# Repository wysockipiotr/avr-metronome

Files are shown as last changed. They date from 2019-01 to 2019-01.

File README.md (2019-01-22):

<h1 align="center">AVR Metronome</h1>
<h5 align="center">Metronome with speaker and remote vibration module</h5>

#### Modules
<table>
<tr>
  <td style="text-align: center">
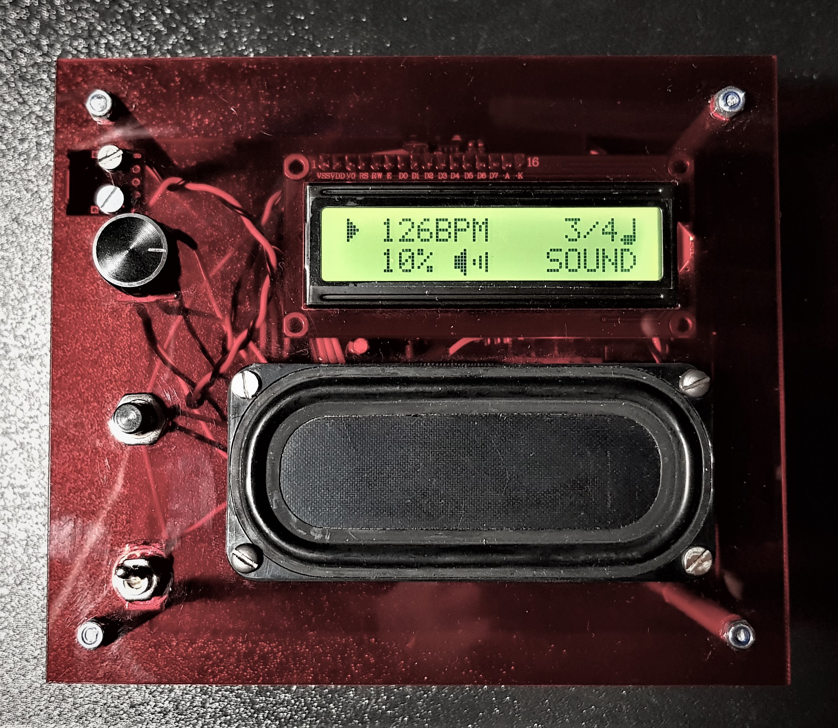
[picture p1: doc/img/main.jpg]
    
  </td>
  <td style="text-align: center">
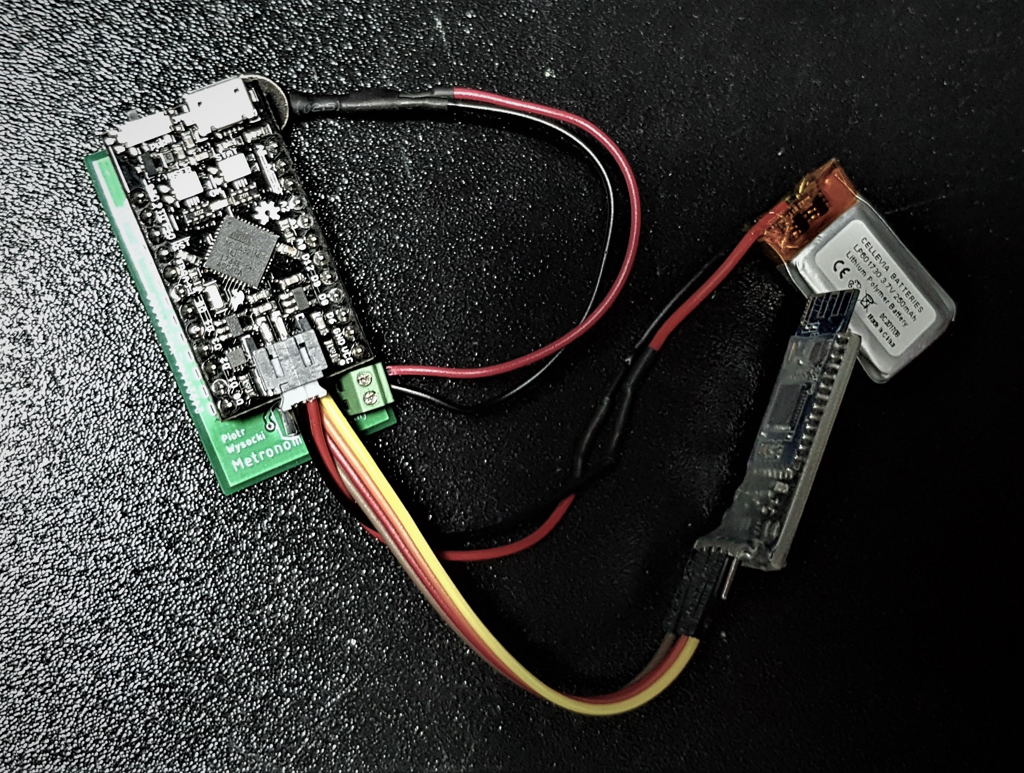
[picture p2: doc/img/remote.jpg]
    
  </td>
</tr>
</table>

#### Built with
- ATmega 168A-PU
- Qduino Mini
- MCP4161
- TPA2005D1
- HM-10 BLE

#### Features
- [x] Sound mode with volume control
- [x] Rotary encoder (with push button) user interface
- [x] BPM and basic signatures control
- [x] Tap tempo (button)
- [x] PWM LCD backlight (dimming after a period of inactivity)
- [x] Storing metronome settings in the internal EEPROM
- [x] Custom character display
- [x] Remote vibration module (BLE)
- [x] Default idle state for remote module, receiving disable signal
- [x] MicroUSB charging
- [x] Adjustable sound pitch

#### Project structure
```c
+-- 
   +-- README.md
   +-- .gitignore
   +-- doc
      +-- eagle
         +-- main
         +-- remote
   +-- metronome          // ATmega metronome main module directory
      +-- Makefile        // compiler and programmer config
      +-- main.c          // entry point
      +-- setup.h         // device main settings
      +-- util.h          // helper macros
      +-- global.h        // extern declarations
      +-- lcd.h           // LCD 2x16 interfacing in 4-bit mode
      +-- lcd.c
      +-- eeprom.h
      +-- eeprom.c
      +-- metronome.h     // core logic of the metronome, ISR handlers
      +-- metronome.c
      +-- usart.h         // serial communication with HM-10 BLE module
      +-- usart.c
      +-- mcp41xx.h       // MCP4161 Digital potentiometer SPI interfacing
      +-- mcp41xx.c
   +-- remote_module      // Qduino (Arduino) remote vibrating module sketch directory
      +-- README.md
      +-- remote_module.ino
```

#### Setup
##### Prerequisites
- make
- avrdude
- avr-gcc
##### Makefile
Override parameters in Makefile to suit your hardware configuration. Here, Arduino Uno is used as an in-system programmer.
```diff
- MCU = atmega168
+ MCU = <your_unit>

- PROGRAMMER_TYPE = avrisp
- PROGRAMMER_ARGS = -b 19200 -P COM4
+ PROGRAMMER_TYPE = <your_programmer_type>
+ PROGRAMMER_ARGS = -b <baud_rate> -P <device_name>
```
##### Deployment
Use `make flash` to compile and save program in flash memory (using `avrdude`). Use `make size` to find out about the size of the program.

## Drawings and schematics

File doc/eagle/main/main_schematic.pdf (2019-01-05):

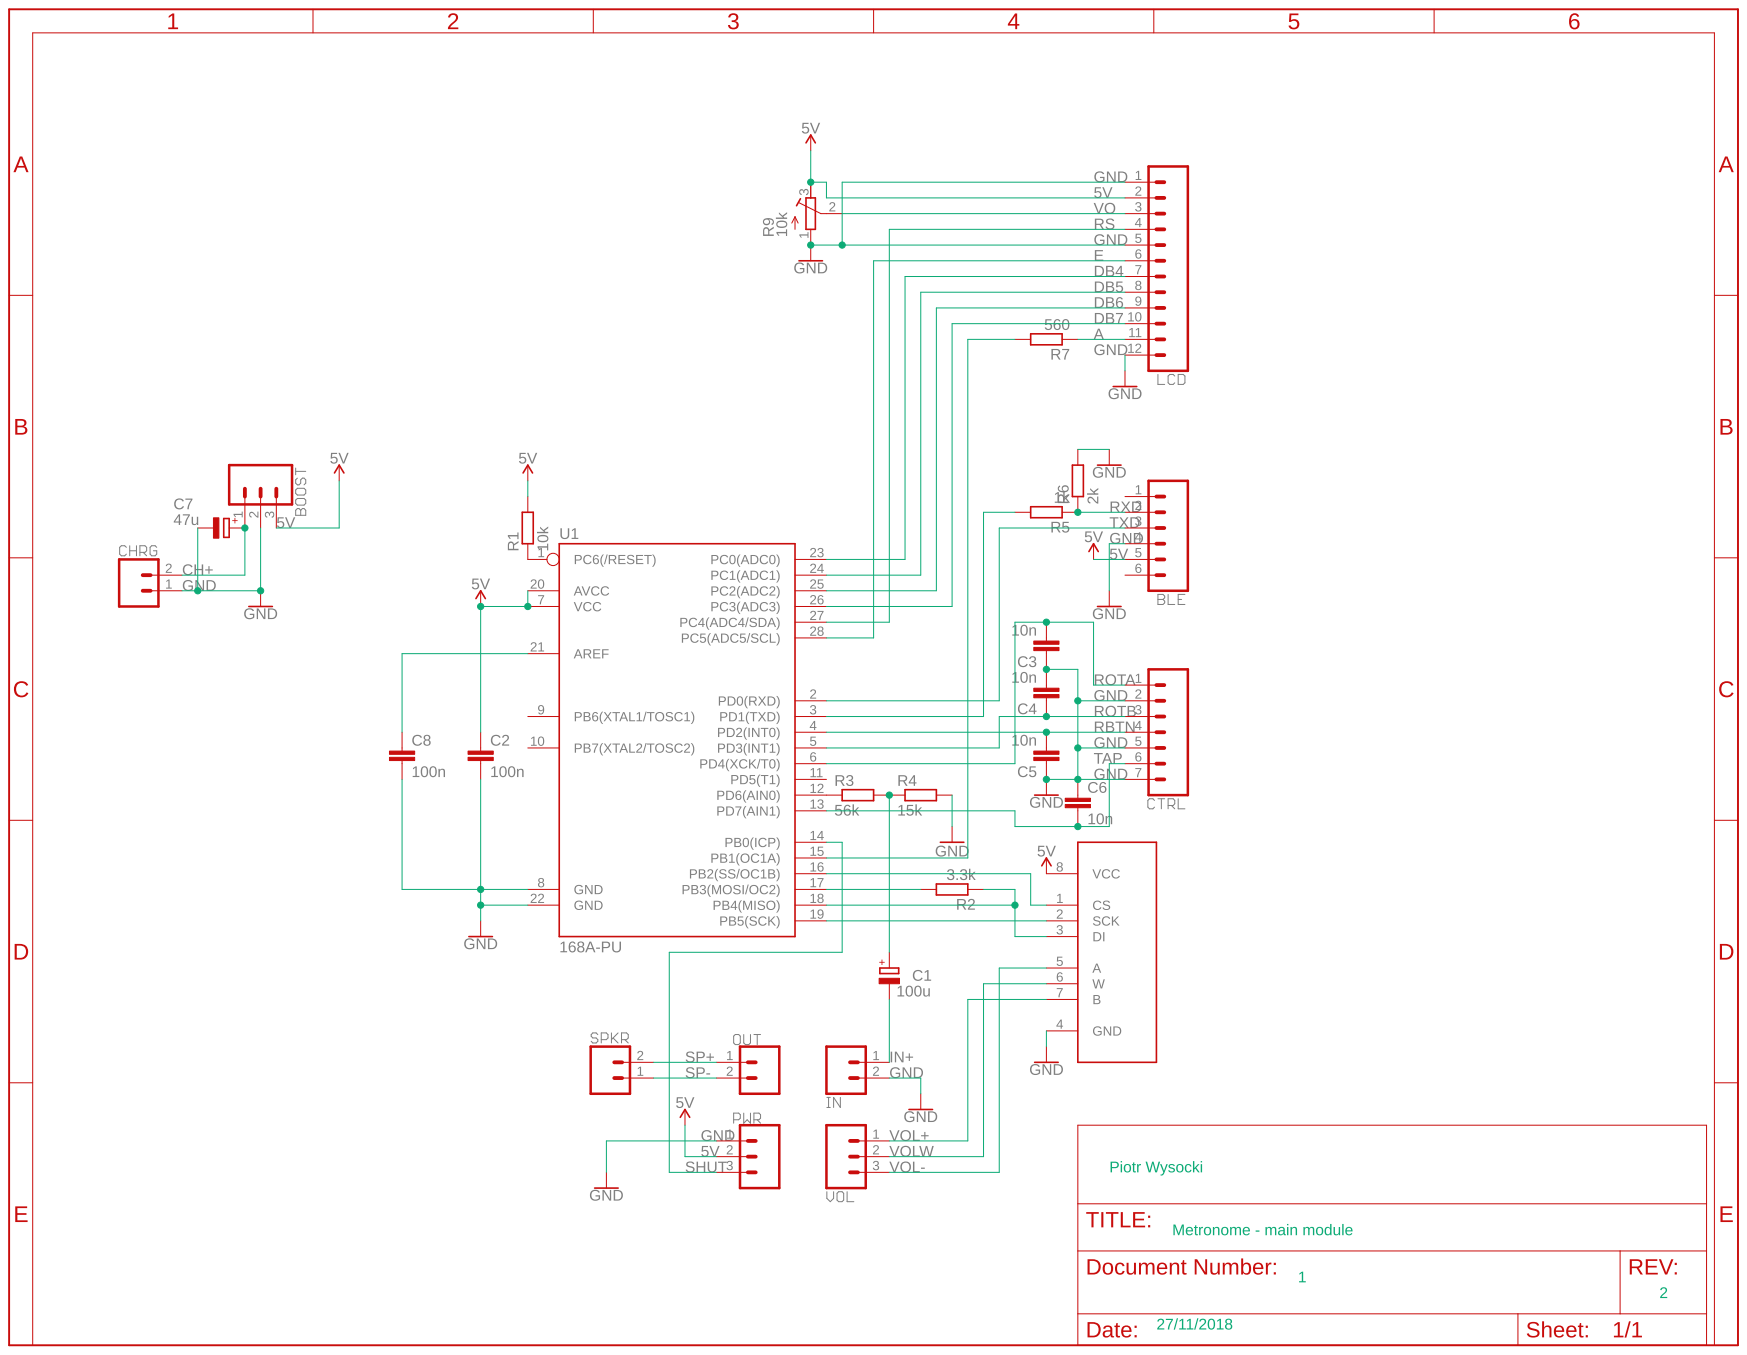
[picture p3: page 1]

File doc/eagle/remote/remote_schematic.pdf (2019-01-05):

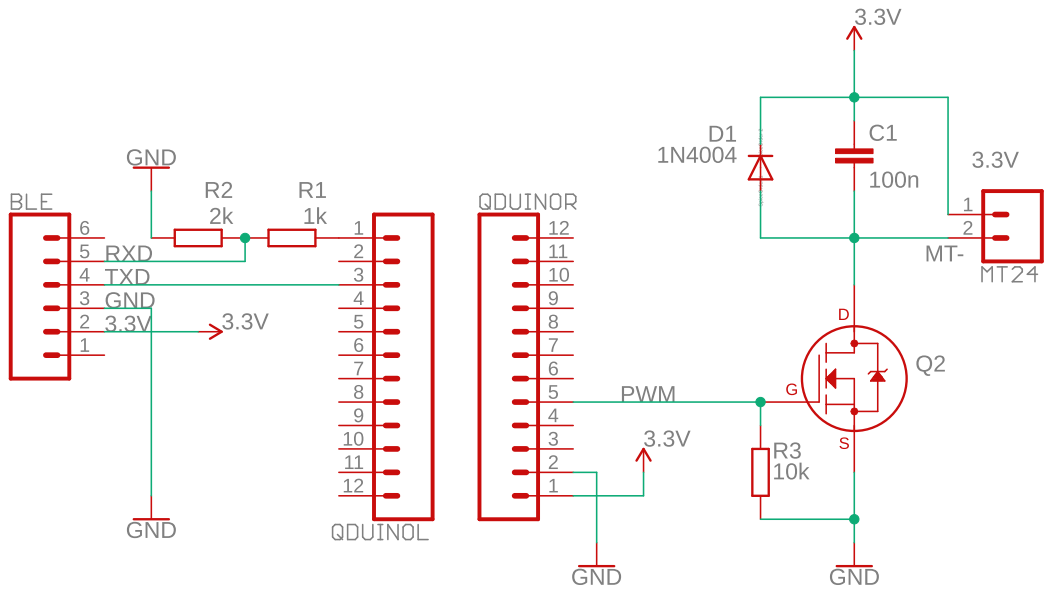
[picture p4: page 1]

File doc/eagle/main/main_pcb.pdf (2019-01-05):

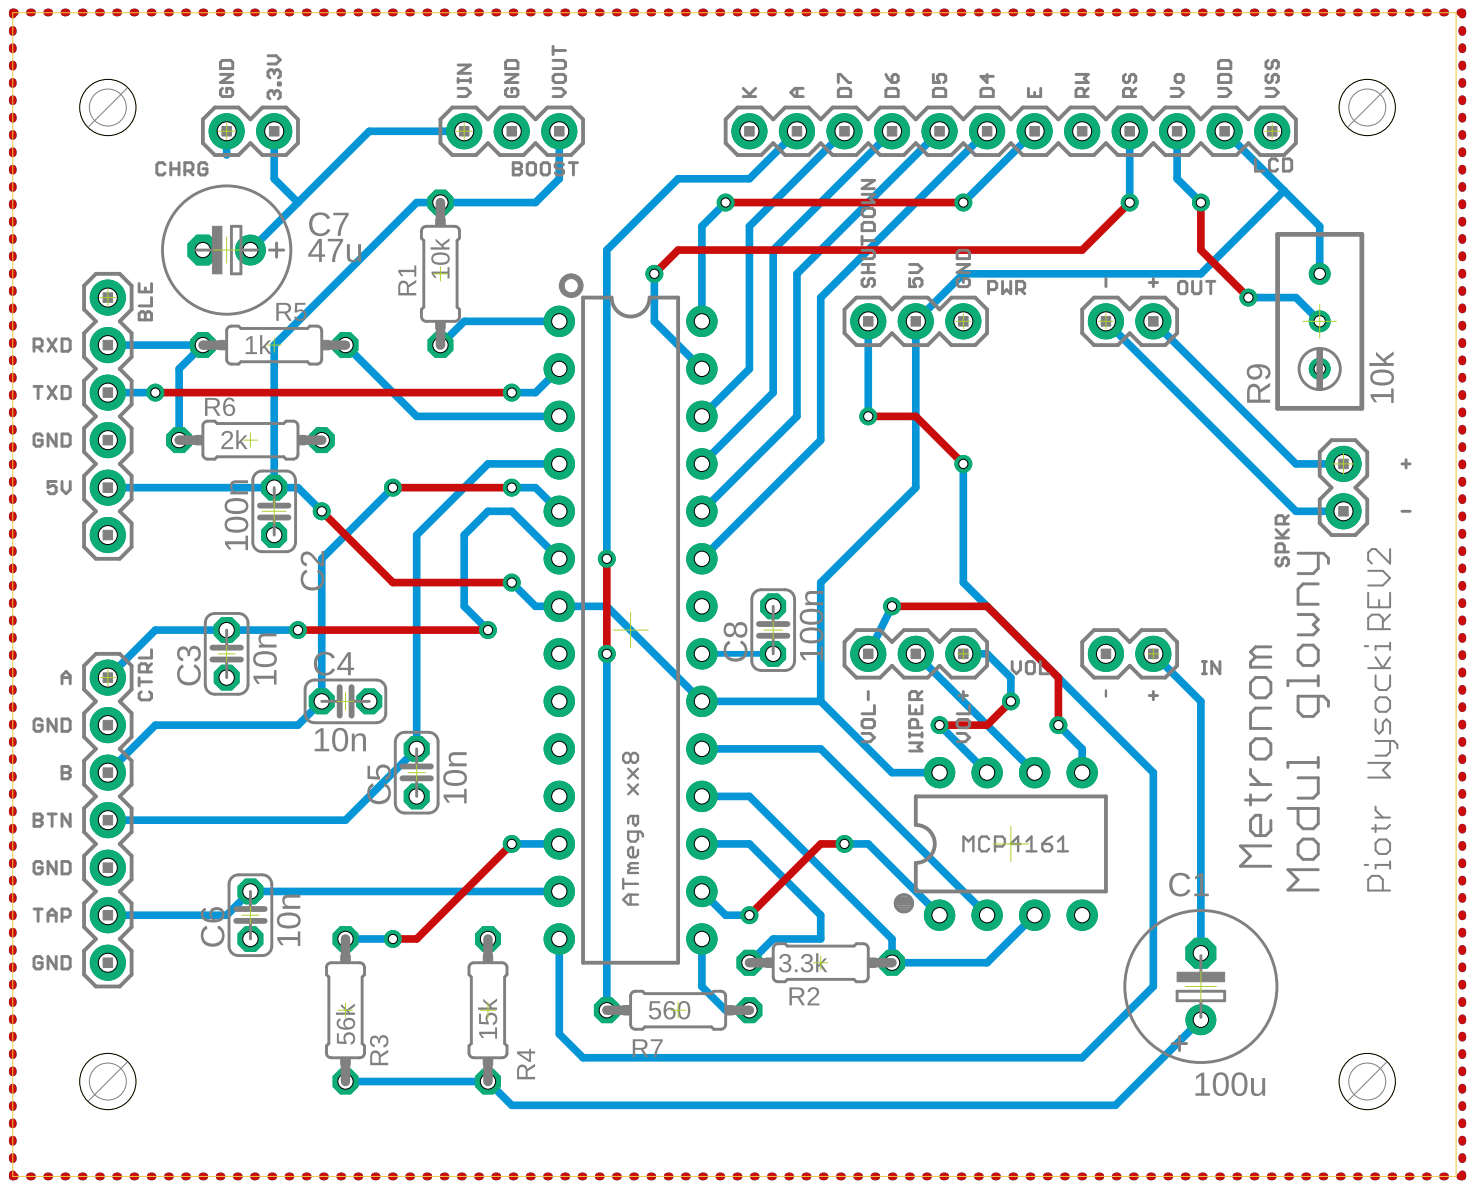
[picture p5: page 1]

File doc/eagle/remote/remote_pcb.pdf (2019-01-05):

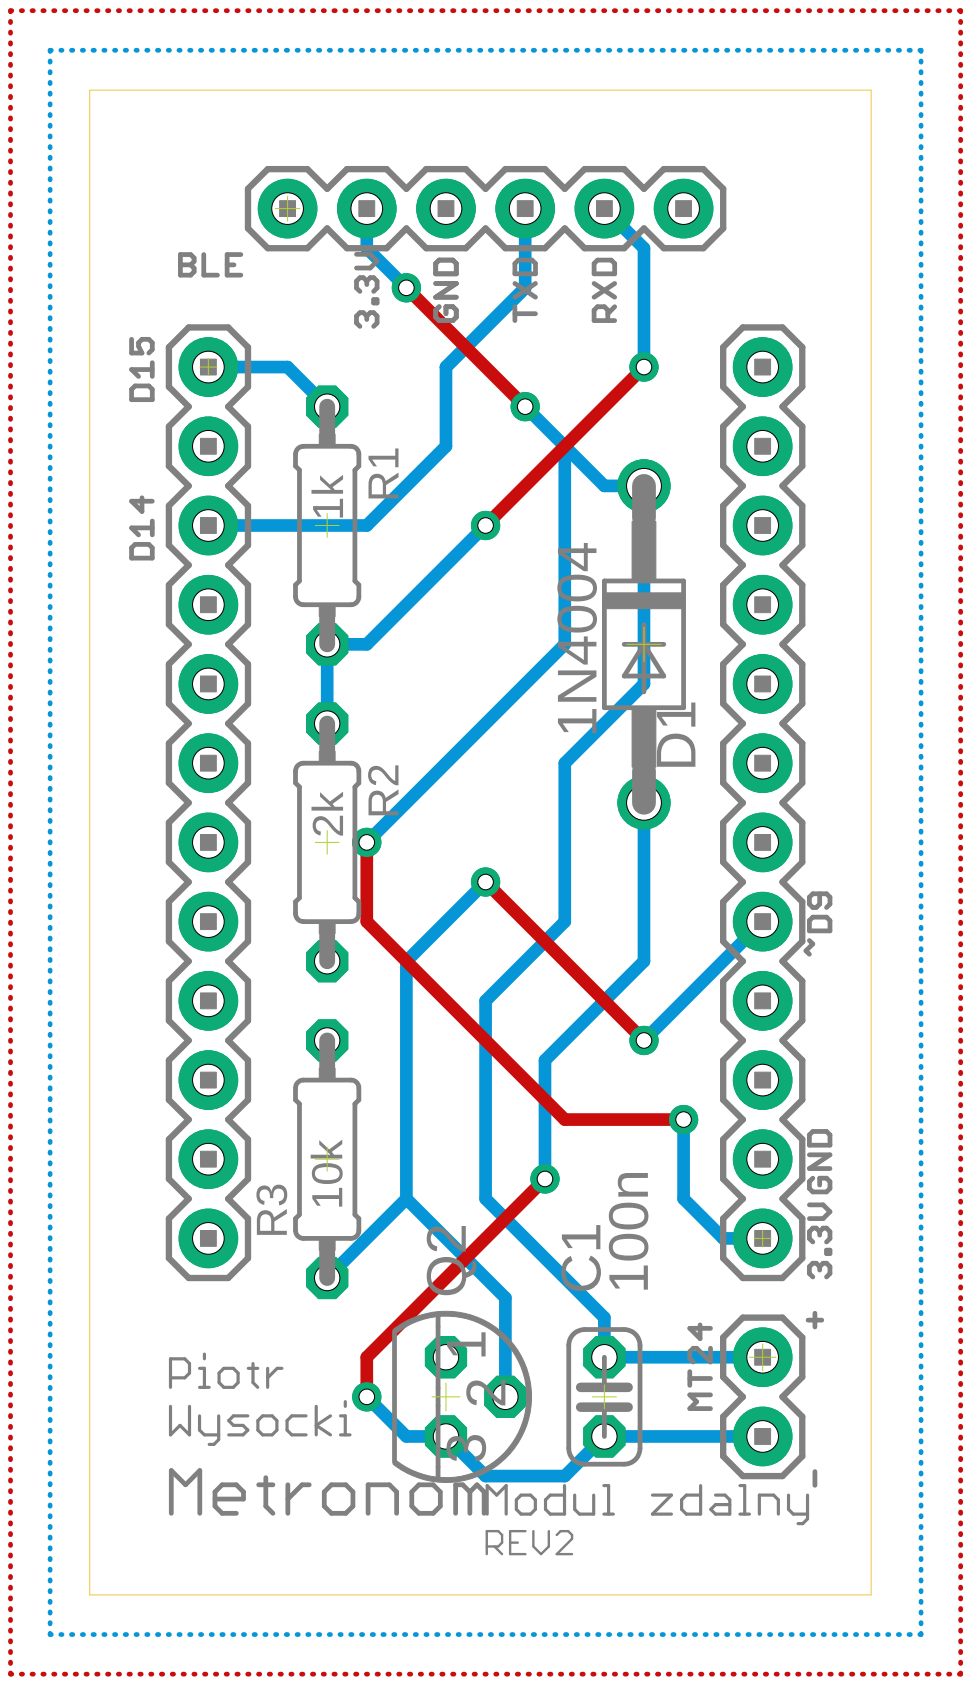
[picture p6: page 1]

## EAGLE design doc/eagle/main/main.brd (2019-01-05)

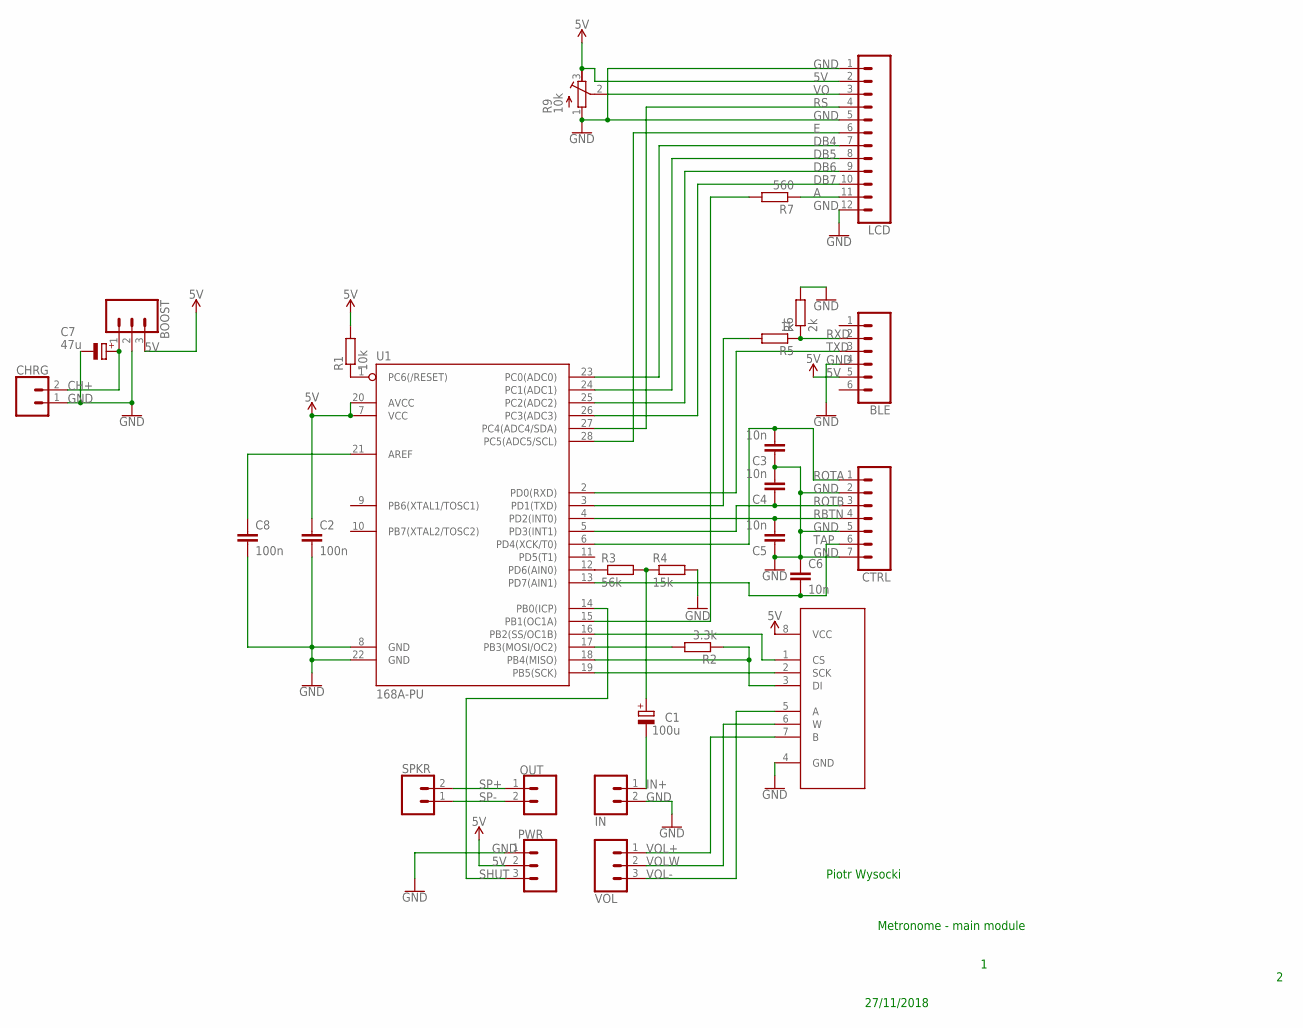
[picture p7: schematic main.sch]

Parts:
BLE: CONN_06SILK_FEMALE_PTH; 1X06
BOOST: CONN_03; 1X03
C1: 100u; E3,5-8
C2, C8: 100n; C025-024X044
C3, C4, C5, C6: 10n; C025-024X044
C7: 47u; E2,5-7
CHRG: CONN_02; 1X02
CTRL: CONN_07; 1X07
IN: CONN_02; 1X02
LCD: CONN_12; 1X12
MCP4161: MCP41XXX; DIP08
OUT: CONN_02; 1X02
PWR: CONN_03; 1X03
R1: 10k; 0204/7
R2: 3.3k; 0204/7
R3: 56k; 0204/7
R4: 15k; 0204/7
R5: 1k; 0204/7
R6: 2k; 0204/7
R7: 560; 0204/7
R9: 10k; RTRIM3296W
SPKR: CONN_02; 1X02
U1: 168A-PU; DIP28
VOL: CONN_03; 1X03

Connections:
5V: BLE.5, BOOST.3, C2.1, LCD.2, MCP4161.8 (VCC), PWR.2, R1.2, R9.3 (E), U1.7 (VCC), U1.20 (AVCC)
A: LCD.11, R7.1
CH+: BOOST.1, C7.+, CHRG.2
DB4: LCD.7, U1.23 (PC0(ADC0))
DB5: LCD.8, U1.24 (PC1(ADC1))
DB6: LCD.9, U1.25 (PC2(ADC2))
DB7: LCD.10, U1.26 (PC3(ADC3))
E: LCD.6, U1.28 (PC5(ADC5/SCL))
GND: BLE.4, BOOST.2, C2.2, C3.1, C4.2, C5.1, C6.1, C7.-, C8.2, CHRG.1, CTRL.2, CTRL.5, CTRL.7, IN.2, LCD.1, LCD.5, LCD.12, MCP4161.4 (GND), PWR.1, R4.2, R6.2, R9.1 (A), U1.8 (GND), U1.22 (GND)
IN+: C1.-, IN.1
unnamed: MCP4161.2 (SCK), U1.19 (PB5(SCK))
unnamed: MCP4161.1 (CS), U1.16 (PB2(SS/OC1B))
unnamed: R1.1, U1.1 (PC6(/RESET))
unnamed: R2.2, U1.17 (PB3(MOSI/OC2))
unnamed: MCP4161.3 (DI), R2.1, U1.18 (PB4(MISO))
unnamed: C8.1, U1.21 (AREF)
unnamed: R3.1, U1.12 (PD6(AIN0))
unnamed: C1.+, R3.2, R4.1
unnamed: R5.2, U1.3 (PD1(TXD))
unnamed: R7.2, U1.15 (PB1(OC1A))
RBTN: C5.2, CTRL.4, U1.4 (PD2(INT0))
ROTA: C3.2, CTRL.1, U1.6 (PD4(XCK/T0))
ROTB: C4.1, CTRL.3, U1.5 (PD3(INT1))
RS: LCD.4, U1.27 (PC4(ADC4/SDA))
RXD: BLE.2, R5.1, R6.1
SHUT: PWR.3, U1.14 (PB0(ICP))
SP+: OUT.1, SPKR.2
SP-: OUT.2, SPKR.1
TAP: C6.2, CTRL.6, U1.13 (PD7(AIN1))
TXD: BLE.3, U1.2 (PD0(RXD))
VO: LCD.3, R9.2 (S)
VOL+: MCP4161.7 (B), VOL.1
VOL-: MCP4161.5 (A), VOL.3
VOLW: MCP4161.6 (W), VOL.2

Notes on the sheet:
Metronome - main module
Piotr Wysocki
27/11/2018

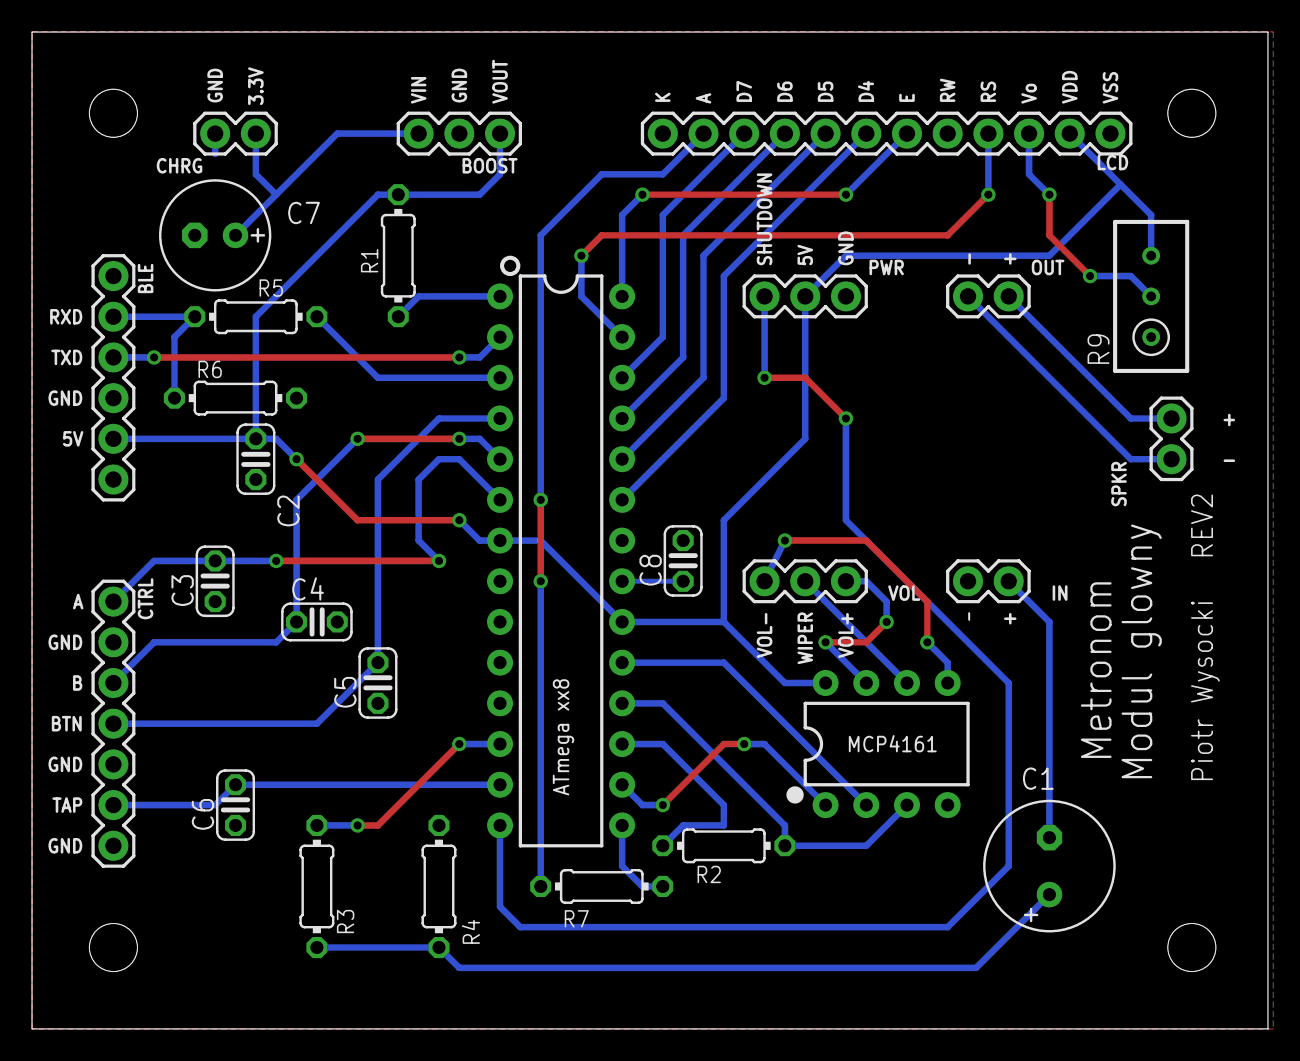
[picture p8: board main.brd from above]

Board: 2 copper layers, 77.1 x 62.2 mm, 28 parts (0 on the bottom side), 34 nets.

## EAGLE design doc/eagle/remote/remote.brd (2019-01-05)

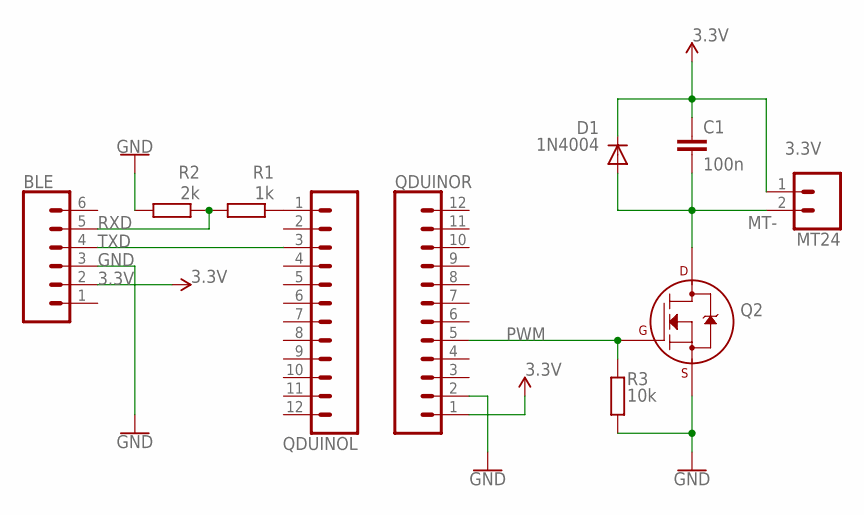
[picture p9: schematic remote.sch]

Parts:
BLE: CONN_06SILK_FEMALE_PTH; 1X06
C1: 100n; C025-024X044
D1: 1N4004; DO41-10
MT24: CONN_02; 1X02
Q2: 2N7000_TO92; TO-92
QDUINOL: CONN_12; 1X12
QDUINOR: CONN_12; 1X12
R1: 1k; 0204/7
R2: 2k; 0204/7
R3: 10k; 0204/7

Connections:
3.3V: BLE.2, C1.1, D1.C, MT24.1, QDUINOR.1
GND: BLE.3, Q2.1 (S), QDUINOR.2, R2.2, R3.2
MT-: C1.2, D1.A, MT24.2, Q2.3 (D)
unnamed: QDUINOL.1, R1.1
PWM: Q2.2 (G), QDUINOR.5, R3.1
RXD: BLE.5, R1.2, R2.1
TXD: BLE.4, QDUINOL.3

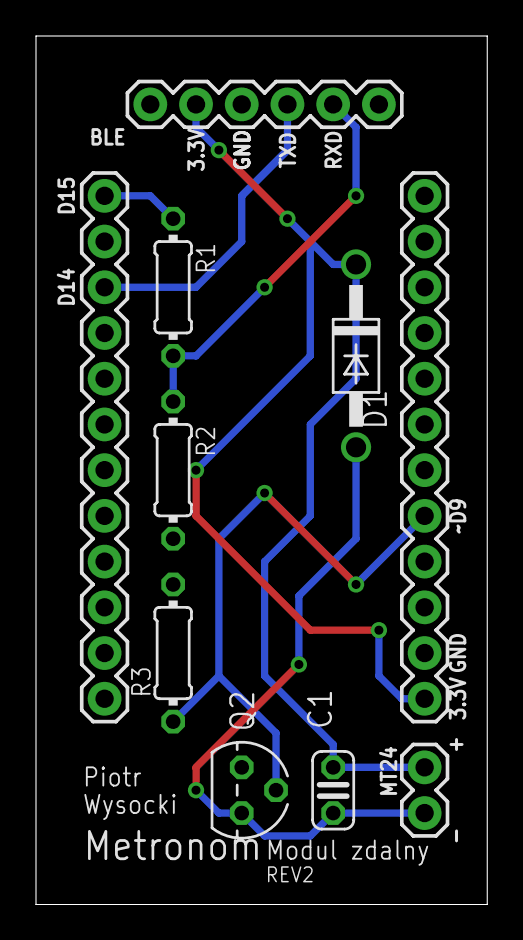
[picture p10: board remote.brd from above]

Board: 2 copper layers, 25.1 x 48.2 mm, 10 parts (0 on the bottom side), 7 nets.

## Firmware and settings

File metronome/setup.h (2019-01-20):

#ifndef __setup_h__
#define __setup_h__

#ifdef F_CPU
    #if F_CPU != 8000000
        #undef F_CPU
        #define F_CPU 8000000
    #endif
#endif

#ifndef BAUD
    #define BAUD 9600
#endif

#include <avr/io.h>
#include "lcd.h"

#define LCD_DIR                     DDRC  
#define LCD_DATA_DIR                DDRC
#define LCD_CMD_DIR                 DDRC
#define LCD_DATA_PORT               DDRC 
#define LCD_CMD_PORT                PORTC
#define LCD_PORT                    PORTC 
#define RS                          PC4 
#define EN                          PC5
#define LCD_D4                      PC0 
#define LCD_D5                      PC1   
#define LCD_D6                      PC2   
#define LCD_D7                      PC3   

#define ROTARY_PORT                 PORTD
#define ROTARY_BTN                  PD2
#define ROTARY_PIN                  PIND
#define ROTARY_DIR                  DDRD
#define ROTARY_A                    PD3
#define ROTARY_B                    PD4

#define SPEAKER_DIR                 DDRD
#define SPEAKER_PORT                PORTD
#define SPEAKER                     PD6
#define SPEAKER_PIN                 PIND

#define TAP_DIR                     DDRD
#define TAP_PORT                    PORTD
#define TAP_PIN                     PIND
#define TAP_BTN                     PD7

#define SHUTDOWN_DIR                DDRB
#define SHUTDOWN_PORT               PORTB
#define SHUTDOWN_PIN                PINB
#define SHUTDOWN                    PB0

#define BACKLIGHT_DIR               DDRB
#define BACKLIGHT_PORT              PORTB
#define BACKLIGHT_PIN               PINB
#define BACKLIGHT                   PB1

// SPI
#define SPI_POT_SS                  PB2
#define SPI_POT_SS_PORT             PORTB
#define SPI_POT_SS_PIN              PINB
#define SPI_POT_SS_DDR              DDRB

#define SPI_MOSI                    PB3
#define SPI_MOSI_PORT               PORTB
#define SPI_MOSI_PIN                PINB
#define SPI_MOSI_DDR                DDRB

#define SPI_MISO                    PB4
#define SPI_MISO_PORT               PORTB
#define SPI_MISO_PIN                PINB
#define SPI_MISO_DDR                DDRB

#define SPI_SCK                     PB5
#define SPI_SCK_PORT                PORTB
#define SPI_SCK_PIN                 PINB
#define SPI_SCK_DDR                 DDRB

#define TAP_TIMER_INITIAL_OFFSET    0x83
#define MIN_TAP_INTERVAL            150u
#define MAX_TAP_INTERVAL            2000u

#define BACKLIGHT_DURATION          20000u  // 20s
#define DEFAULT_BRIGHTNESS          120u

#define MIN_BPM                     30u
#define MAX_BPM                     400u
#define MIN_VOLUME                  0u
#define MAX_VOLUME                  100u
#define VOLUME_STEP                 5u
#define DEFAULT_BPM                 140u
#define DEFAULT_VOL                 5u
#define DEFAULT_SIGNATURE           4u
#define MIN_SIGNATURE               1u 
#define MAX_SIGNATURE               16u
#define G                           33u
#define CIS                         47u
#define TAP_NOTE                    120u
#define TAP_BEEP_DURATION           100u

#define BPM_CURSOR_POS              0u
#define SIG_CURSOR_POS              1u 
#define VOL_CURSOR_POS              2u
#define MODE_CURSOR_POS             3u
#define PITCH_CURSOR_POS            4u

#define PARAM_EDIT_SYMBOL           LCD_ARROWS_CHAR
#define PARAM_SELECT_SYMBOL         LCD_FAT_ARROW_CHAR

#define SOUND_LABEL                 "SOUND"
#define VIBRT_LABEL                 "VIBRT"

#define SOUND_MODE                  0u 
#define VIBRT_MODE                  1u
#define DEFAULT_MODE                SOUND_MODE

#define NUMBER_OF_MODES             2
// #define NUMBER_OF_SIGNATURES        4

#define EEPROM_STORE_ADR            0
#define EEPROM_STORE_BPM            ((uint16_t*)EEPROM_STORE_ADR)
#define EEPROM_STORE_VOL            ((uint8_t*)EEPROM_STORE_ADR + 2)
#define EEPROM_STORE_SIG            ((uint8_t*)EEPROM_STORE_ADR + 3)
#define EEPROM_STORE_MODE           ((uint8_t*)EEPROM_STORE_ADR + 4)
#define EEPROM_STORE_PITCH          ((uint8_t*)EEPROM_STORE_ADR + 5)

// sound scale
#define D2                          89
#define Dx2                         84
#define E2                          79
#define F2                          75
#define Fx2                         71
#define G2                          67
#define Gx2                         63
#define A2                          59
#define Ax2                         56
#define B2                          53
#define C3                          50
#define Cx3                         47
#define D3                          44
#define Dx3                         42
#define E3                          40
#define F3                          37
#define Fx3                         35
#define G3                          33

#define DEFAULT_PITCH_INDEX         11u
#define MAX_PITCH_INDEX             11u
#define MIN_PITCH_INDEX             0u
#define ACCENT_PITCH_OFFSET         6u

#endif //__setup_h__

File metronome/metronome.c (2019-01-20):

#include "metronome.h"
#include "eeprom.h"
#include "global.h"
#include "mcp41xx.h"
#include "usart.h"
#include "util.h"

#include <avr/interrupt.h>
#include <avr/pgmspace.h>
#include <avr/power.h>
#include <stdio.h>
#include <util/delay.h>

// load initial settings, setup peripherals and ports
inline static void setup(void);

// enable interrupts, specify pin change interrupts mask
inline static void init_interrupts(void);

// init timer2 (tap tempo timer), enable its overflow interrupt
inline static void init_tap_timer(void);

// init timer0 (sound synthesize timer)
inline static void init_sound_timer(void);

// main metronome action loop
inline static void loop(void);

// play note with a given wavelength for a given duration
inline static void play_note(uint16_t wavelength, uint8_t duration);

// refresh displayed values and cursor arrow position
inline static void update_display(void);

// update value of the currently selected parameter by the given delta
inline static void update_active_param(int delta);

// recalc beep and silence durations regarding current bpm value
inline static void recalc_durations(void);

// init timer1 in Fast PWM mode (for dimming lcd backlight)
inline static void init_dimmer_pwm(void);

// set lcd backlight brightness (PWM)
inline static void set_brightness(uint8_t brightness);

inline static uint8_t get_tone(uint8_t tone_index);

const static uint8_t tone_table[] PROGMEM = {D2, Dx2, E2, F2, Fx2, G2, Gx2, A2, Ax2,
                                             B2, C3, Cx3, D3, Dx3, E3, F3, Fx3, G3};

void metronome(void) {
    setup();
    loop();
}

void handle_portd_pin_change(void) {
    set_brightness(DEFAULT_BRIGHTNESS);
    backlight_on = true;
    backlight_time_counter = 0u;

    clearBit(SPEAKER_DIR, SPEAKER);

    if (bit_is_clear(ROTARY_PIN, ROTARY_BTN)) {
        if (mode == VIBRT_MODE && edit_active) {
            transmit_metronome(bpm, signature);
        } 
        if (mode == SOUND_MODE && edit_active) {
            transmit_metronome_off();
        }
        edit_active = !edit_active;
        cursor_symbol = (edit_active) ? PARAM_EDIT_SYMBOL : PARAM_SELECT_SYMBOL;
        update_display();
    }

    if (bit_is_clear(ROTARY_PIN, ROTARY_A)) {
        if (bit_is_clear(ROTARY_PIN, ROTARY_B)) {
            // left rotate
            if (!edit_active) {
                if (cursor) {
                    --cursor;
                } else {
                    cursor = 4u;
                }
                if (mode == VIBRT_MODE) {
                    if (cursor == 2u) {
                        cursor = 1u;
                    } else if (cursor == 4u) {
                        cursor = 3u;
                    }
                }
            } else {
                update_active_param(-1);
            }
        } else {
            // right rotate
            if (!edit_active) {
                ++cursor;
                cursor %= 5u;
                if (mode == VIBRT_MODE) {
                    if (cursor == 2u) {
                        cursor = 3u;
                    } else if (cursor == 4u) {
                        cursor = 0u;
                    }
                }
            } else {
                update_active_param(1);
            }
        }

        recalc_durations();

        update_display();

        // force a little down time before continuing
        _delay_ms(2);

        // wait until R1 comes back high
        while (bit_is_clear(ROTARY_PIN, ROTARY_A)) {
        }
    }

    if (bit_is_clear(TAP_PIN, TAP_BTN)) {
        edit_active = false;
        cursor_symbol = (edit_active) ? PARAM_EDIT_SYMBOL : PARAM_SELECT_SYMBOL;

        bool tap_interval_is_within_range = within(tap_interval_counter, MIN_TAP_INTERVAL, MAX_TAP_INTERVAL);

        // beep during tap
        if (tap_interval_is_within_range || !tap_started) {
            sound_locked = false;
            if (mode == VIBRT_MODE) setBit(SHUTDOWN_PORT, SHUTDOWN);
            play_note(TAP_NOTE, TAP_BEEP_DURATION);
            sound_locked = true;
        }

        // tap tempo handler
        if (tap_started) {
            if (tap_interval_is_within_range) {
                t_beep = tap_interval_counter >> 4;
                t_sleep = tap_interval_counter - t_beep;
                bpm = 60000u / tap_interval_counter;
                update_display();
            }
        } else {
            tap_started = true;
            sound_locked = true;
        }
        // start counting
        tap_interval_counter = 0u;
        //TCCR2A = 0;
        TCCR2B = 0x4;
        TCNT2 = TAP_TIMER_INITIAL_OFFSET;  // 131 ticks until overflow (overflow every 1ms)
    }
}

void handle_timer2_overflow(void) {
    // handle tap tempo
    if (tap_interval_counter <= MAX_TAP_INTERVAL) {
        ++tap_interval_counter;
        // TCNT2 = TAP_TIMER_INITIAL_OFFSET;
    } else {
        // dismiss tap tempo in case of timeout (over 2000ms)
        if (tap_started) {
            tap_started = false;
            if (mode == VIBRT_MODE) {
                transmit_metronome(bpm, signature);
                clearBit(SHUTDOWN_PORT, SHUTDOWN);
            }
            sound_locked = false;
        }
        //TCCR2B &= ~(TCCR2B & 0x7);
    }

    // handle backlight and settings storage
    if (backlight_time_counter <= BACKLIGHT_DURATION) {
        ++backlight_time_counter;
    } else {
        if (backlight_on) {
            backlight_on = false;
            set_brightness(0);
            //backlight_time_counter = 0u;

            // store current metronome settings in eeprom (bpm, signature, volume, mode)
            eeprom_store_settings();
        }
    }

    // restart 1ms measure
    TCNT2 = TAP_TIMER_INITIAL_OFFSET;
}

inline static void update_display(void) {
    if (cursor <= MODE_CURSOR_POS) {
        // Menu page (1): bpm, signature, volume (in sound mode), mode

        snprintf(firstLineBuffer, 17, "%c %3uBPM %c %2u/4 ",
                 cursorVisible(cursor, 0, cursor_symbol),
                 bpm,
                 cursorVisible(cursor, 1, cursor_symbol),
                 signature);

        if (mode == SOUND_MODE) {
            // second line of menu in sound mode

            snprintf(secondLineBuffer, 17, "%c %2u%%    %c %s",
                     cursorVisible(cursor, 2, cursor_symbol),
                     volume % 100,
                     cursorVisible(cursor, 3, cursor_symbol),
                     SOUND_LABEL);

            if (volume == 100) {
                secondLineBuffer[2] = 'M';
                secondLineBuffer[3] = 'A';
                secondLineBuffer[4] = 'X';
                secondLineBuffer[5] = ' ';
            }

            secondLineBuffer[6] = LCD_SPEAKER_CHAR;
            secondLineBuffer[7] = (volume > 0) ? LCD_WAVE_CHAR : ' ';
        } else {
            // second line of menu in vibration mode

            snprintf(secondLineBuffer, LCD_SIZE + 1, "         %c %s",
                     cursorVisible(cursor, 3, cursor_symbol),
                     VIBRT_LABEL);
        }

        firstLineBuffer[15] = LCD_NOTE_CHAR;

    } else {
        // Menu page (2): pitch

        char accent_tone_name[4];
        load_tone_name_from_pgm(pitch_index + ACCENT_PITCH_OFFSET, accent_tone_name);
        char main_tone_name[4];
        load_tone_name_from_pgm(pitch_index, main_tone_name);

        snprintf(firstLineBuffer, 17, "%c PITCH %s/ %s",
                 cursor_symbol,
                 accent_tone_name,
                 main_tone_name);

        for (int i = 0; i < LCD_SIZE; ++i) {
            secondLineBuffer[i] = ' ';
        }
    }

    // show interpolated strings
    lcd_string_xy(0, 0, firstLineBuffer);
    lcd_string_xy(1, 0, secondLineBuffer);
}

inline static void update_active_param(int delta) {
    switch (cursor) {
        case BPM_CURSOR_POS:
            if (within(bpm + delta, MIN_BPM, MAX_BPM)) {
                bpm += delta;
            }
            break;

        case SIG_CURSOR_POS:
            if (signature <= MIN_SIGNATURE && delta == -1) {
                signature = MAX_SIGNATURE;
            } else if (signature >= MAX_SIGNATURE && delta == 1) {
                signature = MIN_SIGNATURE;
            } else {
                signature += delta;
            }
            break;

        case VOL_CURSOR_POS:
            delta *= 5;
            if (within(volume + delta, MIN_VOLUME, MAX_VOLUME)) {
                volume += delta;
            }
            mcp_pot_set_percent_value(volume);
            break;

        case MODE_CURSOR_POS:
            if (mode == VIBRT_MODE) {
                // send remote metronome module disable signal
                //transmit_metronome_off();
                mode = SOUND_MODE;
            } else {
                mode = VIBRT_MODE;
            }
            break;

        case PITCH_CURSOR_POS:
            if (pitch_index == MIN_PITCH_INDEX && delta == -1) {
                pitch_index = MAX_PITCH_INDEX;
            } else if (pitch_index >= MAX_PITCH_INDEX && delta == 1) {
                pitch_index = MIN_PITCH_INDEX;
            } else {
                pitch_index += delta;
            }
            break;

        default:
            break;
    }

    // power off audio amp if unnecessary
    if (volume == 0u || mode == VIBRT_MODE) {
        clearBit(SHUTDOWN_PORT, SHUTDOWN);
    } else {
        setBit(SHUTDOWN_PORT, SHUTDOWN);
    }
}

inline static void setup(void) {
    // clk / 1
    clock_prescale_set(CLK_NO_DIVIDE);

    // initial values
    eeprom_load_settings();
    cursor = 0u;
    t_beep = 6000u / bpm;
    t_sleep = 54000u / bpm;
    tap_interval_counter = 0u;
    tap_started = false;
    sound_locked = false;
    edit_active = false;
    cursor_symbol = PARAM_SELECT_SYMBOL;

    lcd_init();
    spi_init();
    usart_init();

    init_dimmer_pwm();

    init_tap_timer();
    init_sound_timer();
    init_interrupts();

    setInputPullup(ROTARY_DIR, ROTARY_PORT, ROTARY_A);
    setInputPullup(ROTARY_DIR, ROTARY_PORT, ROTARY_B);
    setInputPullup(ROTARY_DIR, ROTARY_PORT, ROTARY_BTN);
    setInputPullup(TAP_DIR, TAP_PORT, TAP_BTN);

    setBit(SHUTDOWN_DIR, SHUTDOWN);
    setBit(SHUTDOWN_PORT, SHUTDOWN);

    mcp_pot_set_percent_value(volume);

    backlight_on = true;
    set_brightness(DEFAULT_BRIGHTNESS);

    update_display();
}

inline static void loop(void) {
    uint8_t i = 0u;
    uint16_t t = 0u;

    while (true) {
        if (mode == SOUND_MODE) {
            play_note(get_tone(pitch_index + ACCENT_PITCH_OFFSET), t_beep);

            for (t = t_sleep; t > 0; --t) {
                _delay_ms(1);
            }

            for (i = 0u; i < signature - 1; ++i) {
                play_note(get_tone(pitch_index), t_beep);

                for (t = t_sleep; t > 0; --t) {
                    _delay_ms(1);
                }
            }
        }
    }
}

inline static void init_interrupts(void) {
    // enable pin change interrupts on PORTD
    PCICR |= (1 << PCIE2);

    // pin change interrupt mask
    PCMSK2 |= ((1 << ROTARY_A) | (1 << ROTARY_B) | (1 << TAP_BTN) | (1 << ROTARY_BTN));

    // enable interrupts globally
    sei();
}

inline static void init_tap_timer(void) {
    // enable timer2 overflow interrupt
    TIMSK2 = (1 << TOIE2);

    TCCR2B = 0x4;
    TCNT2 = TAP_TIMER_INITIAL_OFFSET;  // 131 ticks until overflow
    backlight_time_counter = 0u;
}

inline static void init_sound_timer(void) {
#ifdef SINE_WAVE
    TCCR0A |= (1 << COM0A1);       /* wyjście PWM z rejestru OCR0A */
    SPEAKER_DIR |= (1 << SPEAKER); /* włącz pin wyjściowy */

    TCCR0A |= (1 << WGM00); /* szybki tryb PWM */
    TCCR0A |= (1 << WGM01); /* szybki tryb PWM, część 2 */

    TCCR0B |= (1 << CS00);
#else
    setBit(TCCR0A, WGM01);
    setBit(TCCR0A, COM0A0);
    setBit(TCCR0B, CS00);
    setBit(TCCR0B, CS01);
#endif
}

inline static void recalc_durations(void) {
    t_beep = 6000u / bpm;
    t_sleep = 54000u / bpm;
}

inline static void play_note(uint16_t wavelength, uint8_t duration) {
    OCR0A = wavelength;
    if (!sound_locked && !edit_active) {
        setBit(SPEAKER_DIR, SPEAKER);
        while (duration) {
            _delay_ms(1u);
            --duration;
        }
        clearBit(SPEAKER_DIR, SPEAKER);
    }
}

inline static void init_dimmer_pwm(void) {
    setBit(TCCR1A, WGM10);
    //setBit(TCCR1A, WGM13);
    //setBit(TCCR1A, WGM11);
    setBit(TCCR1A, WGM12);

    setBit(TCCR1B, CS11);
    //setBit(TCCR1B, CS10);
    setBit(TCCR1A, COM1A1);

    // enable PWM output
    setBit(BACKLIGHT_DIR, BACKLIGHT);
}

inline static void set_brightness(uint8_t brightness) {
    //OCR1B = OCR1A;
    OCR1A = brightness;
}

inline static uint8_t get_tone(uint8_t tone_index) {
    return pgm_read_byte(tone_table + tone_index);
}

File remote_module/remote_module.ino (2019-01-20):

#define NO_DEBUG

#include <SoftwareSerial.h>

#include "Qduino.h"

#define MOTOR 9  // vibration motor PWM output
#define RX 14    // RX receives from BLE TX
#define TX 15    // TX transmits to BLE RX

#define ACCENT true
#define ACCENT_PWM 250u
#define ACCENT_DUTY 85u
#define ACCENT_COLOR RED
#define NO_ACCENT false
#define NO_ACCENT_PWM 200u
#define NO_ACCENT_DUTY 45u
#define NO_ACCENT_COLOR BLUE
#define IDLE_COLOR GREEN

// tempo in beats per minute
uint16_t bpm;

// metronome period
volatile uint16_t period;

// active time signature
volatile uint8_t signature;

// vibration enabled
volatile bool enabled = false;

// loop iterator
uint8_t i;

// ble buffer iterator
int k = 0;

// ble data buffer
uint16_t ble_buffer[3];

// time signatures
//const uint8_t signatures[4] = {0x44, 0x34, 0x54, 0x74};

// Qduino Mini library
qduino q;

// Bluetooth Low Energy serial
SoftwareSerial ble(RX, TX);

void pulse(uint16_t duration, bool accent);

void read_from_ble();

void setup() {
    pinMode(MOTOR, OUTPUT);

    bpm = 130u;
    period = 60000 / bpm;
    signature = 0x44;

#ifndef NO_DEBUG
    Serial.begin(9600);
#endif
    ble.begin(9600);

    // power on indication
    q.setRGB(IDLE_COLOR);
}

void loop() {
    read_from_ble();

    if (enabled) {
        pulse(period, ACCENT);

        for (i = 0u; i < signature - 1; ++i) {
            read_from_ble();

            pulse(period, NO_ACCENT);
        }
    }
}

void read_from_ble() {
    while (ble.available() > 0) {
        ble_buffer[k++] = ble.read();

        if (k == 3) {
            if (ble_buffer[0] | ble_buffer[1] | ble_buffer[2]) {
                bpm = (ble_buffer[0] << 8) | (ble_buffer[1] & 0xff);
                period = 60000 / bpm;
                signature = ble_buffer[2];
                enabled = true;
            } else {
                enabled = false;
                q.setRGB(IDLE_COLOR);
            }

#ifndef NO_DEBUG
            Serial.print(bpm);
            Serial.print(' ');
            Serial.print(signature);
            Serial.print('/');
            Serial.print('4');
            Serial.print('\n');
#endif
        }
        k %= 3;
    }
}

void pulse(uint16_t duration, bool accent) {
    uint8_t duty = accent ? ACCENT_DUTY : NO_ACCENT_DUTY;
    uint16_t t_high = (uint16_t)(((uint32_t)duration * duty) / 100u);

    analogWrite(MOTOR, accent ? ACCENT_PWM : NO_ACCENT_PWM);
    q.setRGB(accent ? ACCENT_COLOR : NO_ACCENT_COLOR);
    delay(t_high);

    analogWrite(MOTOR, 0);
    q.ledOff();
    delay(duration - t_high);
}

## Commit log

2018-11-20 Interrupts for rotary encoder and buttons, timer0 based sound generator, timer1 based tap tempo, basic metronome
2018-11-21 Added MCP41xx chip interfacing through SPI
2018-11-22 Arduino vibrating module sketch origins
    [remote_module.ino]
2018-11-27 PWM LCD dimmable backlight, metronome mode switching origins
2018-11-27 Eagle main module schematic (version with connectors)
    [metronome-main.sch]
2018-11-27 Updated README.md: setup, schematic
2018-11-30 Vibration motor output"
2018-12-01 Fixed Vibrt mode params update on edit mode exit
    [metronome.c]
2018-12-09 Eagle files, eeprom empty *.h and *.c
    [main.brd, main.sch, remote.brd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]
2018-12-09 View schematics in README file
2019-01-05 Storing metronome params in EEPROM after user inactivity, Eagle files + PDF exports
    [main.brd, main.sch, remote.brd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]
2019-01-20 Pitch tuning, second menu page
2019-01-20 Cursor bug fix, vibrations disable signal on rotary button pushed
    [metronome.c]

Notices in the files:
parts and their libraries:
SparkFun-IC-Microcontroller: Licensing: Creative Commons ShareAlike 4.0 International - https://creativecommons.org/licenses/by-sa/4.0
